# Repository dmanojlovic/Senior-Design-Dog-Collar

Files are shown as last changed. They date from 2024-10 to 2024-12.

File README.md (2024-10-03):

# Senior-Design-Dog-Collar
Welcome to our github page for our senior design project, below is a brief explanation of what is in each folder. Learn more about our progress [here](https://engineering.purdue.edu/477grp5/)

## Hierarchy PCB
This folder contains our PCB schematic in an easy to read format
## PCB
This folder contains our footprints, schematic and symbols for our PCB design
## Server
This folder contains all the files running on the server including the data processing, UART communication and website hosting
## STM
This folder contains all the files needed for the STM32 chip that will be on the dog collar

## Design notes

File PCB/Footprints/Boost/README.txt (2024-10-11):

## WEBENCH Design 21
Created at Fri Oct 11 11:33:55 CDT 2024
**********************************************************
***************** Schematic Instructions  ****************
**********************************************************

To import your new Schematic file into Eagle:

1. Unzip the downloaded folder files to local directory and Start Eagle.
2. Select "File"->"Open"->"Schematic..." from the menu at the top of
the screen.
3. Browse to your newly exported file and select the ".sch" file extension.
4. You should now see your schamtic available in Eagle.

**********************************************************
*******************  PCB Instructions  *******************
**********************************************************

To import your new BOARD file into Eagle:

1. Unzip the downloaded folder files to local directory and Start Eagle.
2. Select "File"->"Open"->"Board..." from the menu at the top of
the screen.
3. Browse to your newly exported file and select the ".brd" file extension.
4. Planes will need to be repoured to update the polygon fills
	1. Once your board is loaded, type "ratsnest" into the command
	   line and press the Enter key.
	2. The polygons should all be filled now.
5. You should now have an image of your board available in Eagle.

**********************************************************
*******************  LIB Instructions  *******************
**********************************************************

To import your new library into Eagle:

1. Start Eagle.
2. Select "File"->"New"->"Library" from the menu.
3. In the blank library window, select "File" -> "Execute Script"
from the menu.
5. Browse to your newly exported Eagle Script file (".scr" file extension)
6. After opening the file, the script will populate the new library.
Layer 93 should NOT exist.
7. Use "File"->Save As: "AcceleratedDesigns_Lib.lbr" and to the desired
location in Eagle native format.
8. Update schematic with the imported library, Select Library and click on Update; open the library file
	and sync. each part.

For additional information, please visit this site:
http://www.accelerated-designs.com/help/Eagle_import.html

You may also find this video helpful:
http://youtu.be/5jGuWY-Yy3Q

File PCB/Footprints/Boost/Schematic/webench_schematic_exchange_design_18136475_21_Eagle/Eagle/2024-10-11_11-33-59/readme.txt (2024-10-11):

 

**********************************************************
*************  Important Instructions Follow  ************
**********************************************************
 
All files exported to: C:\\CADExport\\workspace\Eagle\2024-10-11_11-33-59\2024-10-11_11-33-59

To import your new library into Eagle:
1. Start Eagle.
2. In the control panel window, Select File -> New -> Library from the menu.
3. In the blank library window, select File -> Execute Script from the menu.
5. Browse to your newly exported Eagle Script file (".scr" file extension)
6. After opening the file, the script will populate the new library.
7. Use File -> Save (or Save As..) to save the library to the desired location in Eagle native format.

**************************************************************
**    !!!!!!!!!!!!!        WARNING        !!!!!!!!!!!!!     **
**************************************************************

Besure to check the documentation layer, "48"/"Document", for important information that may seem to be missing or have not translated properly!

For additional information, please visit this site:
http://www.accelerated-designs.com/help/Eagle_import.html

You may also find this video helpful:
http://youtu.be/5jGuWY-Yy3Q

The Symbol WB_LM2735X was missing a Value attribute, a value was created for the symbol.

Ultra Librarian Gold 8.3.103 Process Report

Message - Padstack "RX44Y57D0T" Shape(4) is a CIRCLE with no diameter.
Message - Padstack "RX50Y22D0T" Shape(4) is a CIRCLE with no diameter.
Message - Padstack "RX45Y73D0T" Shape(4) is a CIRCLE with no diameter.
Message - Padstack "RX59Y87D0T" Shape(4) is a CIRCLE with no diameter.
Message - Pattern "SLF7045", entity (115-Line) is a LINE with matching start and end points.
Message - Pattern "SLF7045", entity (117-Line) is a LINE with matching start and end points.
Message - Pattern "SLF7045", entity (119-Line) is a LINE with matching start and end points.
Message - Pattern "SLF7045", entity (121-Line) is a LINE with matching start and end points.
Message - Symbol "WB_CAPACITOR" has as multiple attributes named "TYPE".
One of the attributes was renamed to "TYPE_2".

TextStyle count:  24
Padstack count:   4
Pattern count:    4
Symbol count:     8
Component count:  11

Export

Component "WB_GND" has no mapped footprint will be skipped.
Component "WB_BATTERY" has no mapped footprint will be skipped.
Component "WB_CURRENT_LOAD" has no mapped footprint will be skipped.

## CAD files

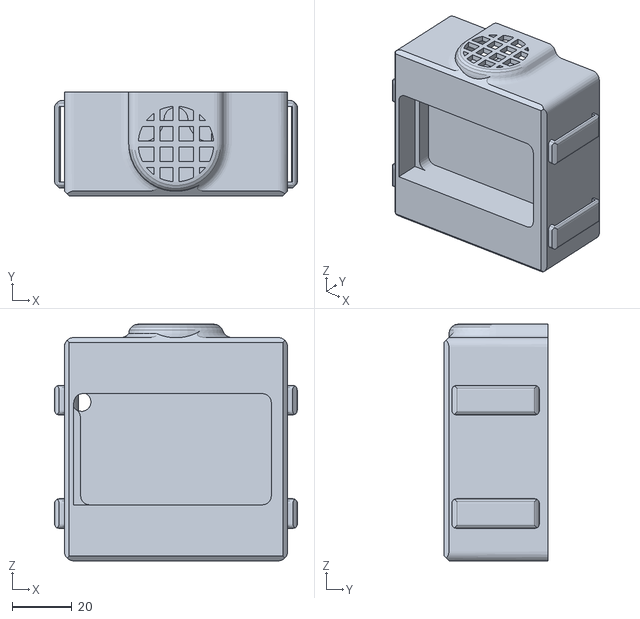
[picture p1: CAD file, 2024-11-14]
3d model/Dog Collar Box V2.2.stl
81.6 x 34.8 x 79.5

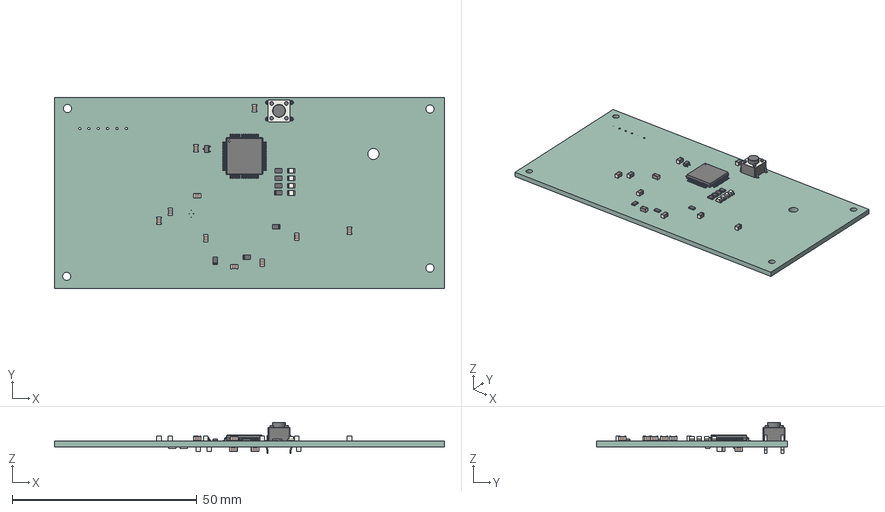
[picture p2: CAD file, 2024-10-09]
PCB/PCB.step
105.5 x 51.8 x 8.50 mm
C_0805_2012Metric x 16
SW_PUSH_6mm_h5mm
LED_0805_2012Metric x 4
R_0805_2012Metric x 9
LQFP_64_10x10mm_P05mm
SOT_323_SC_70
L_0805_2012Metric
_autosave-PCB_PCB

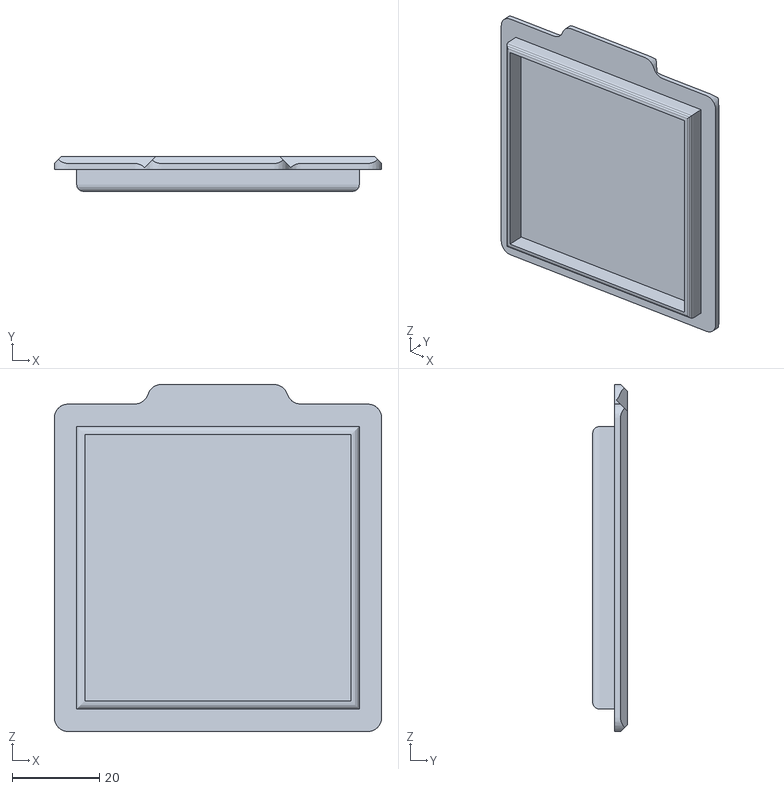
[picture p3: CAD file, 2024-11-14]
3d model/Dog Collar Box Lid V2.2.stl
75.0 x 8.00 x 79.5

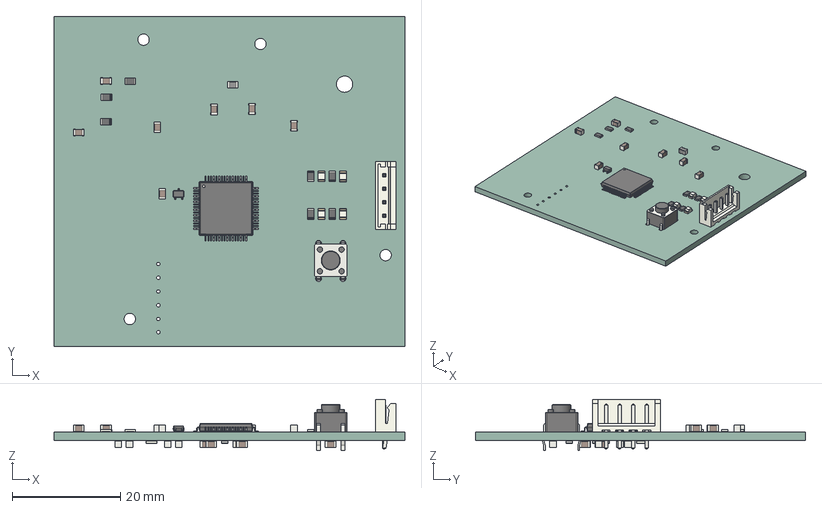
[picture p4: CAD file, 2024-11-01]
3d model/PCB.step
64.8 x 61.0 x 9.50 mm
R_0805_2012Metric x 11
L_0805_2012Metric
LQFP_64_10x10mm_P05mm
SOT_323_SC_70
SW_PUSH_6mm_h5mm
C_0805_2012Metric x 16
LED_0805_2012Metric x 4
JST_B4B_EH_A
PCB_PCB

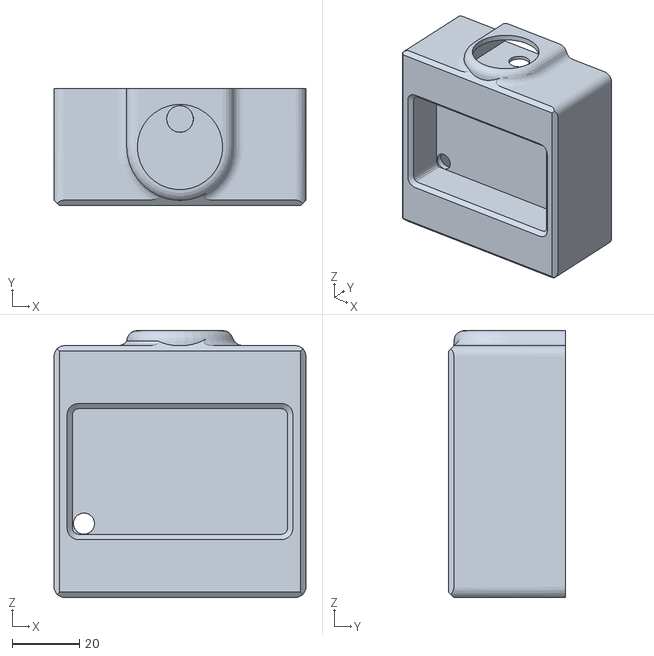
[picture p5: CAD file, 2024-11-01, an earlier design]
3d model/Dog Collar Box V2.1.stl
75.0 x 34.8 x 79.5

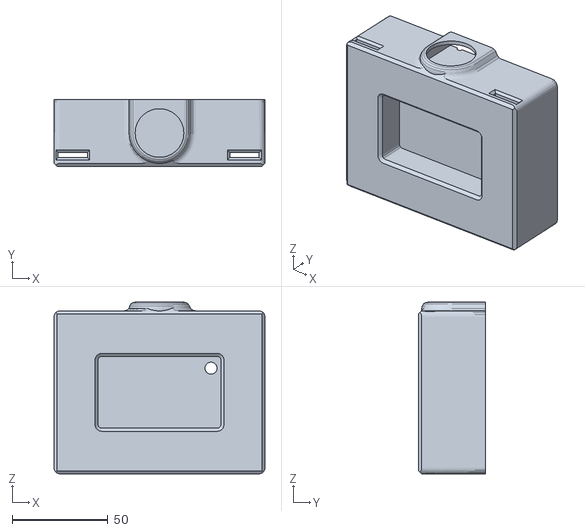
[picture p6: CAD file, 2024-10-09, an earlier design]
3d model/Dog Collar Box Lid V2.0.stl
110.0 x 34.8 x 89.5

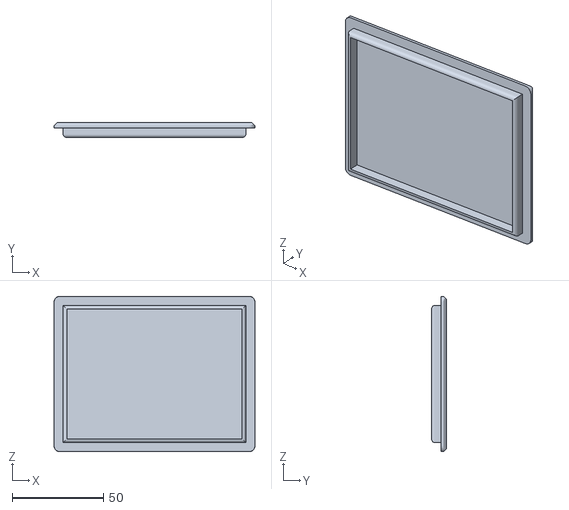
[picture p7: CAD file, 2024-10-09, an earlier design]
3d model/Dog Collar Box Lid V1.0.stl
110.0 x 8.00 x 85.0

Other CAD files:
3d model/Dog Collar Box V1.0.stl
3d model/Battery box.ipt
3d model/Dog Collar Box V1.0.iam
3d model/Dog Collar Box V1.0.idw
3d model/Lid.ipt
3d model/OldVersions/Battery box.0001.ipt
3d model/OldVersions/Dog Collar Box V1.0.0003.idw
3d model/OldVersions/Dog Collar Box V1.0.0007.iam
3d model/OldVersions/Lid.0004.ipt
3d model/OldVersions/PCB Holder.0005.ipt
3d model/PCB Holder.ipt
3d model/PCB/C_0805_2012Metric.iam
3d model/PCB/C_0805_2012Metric.ipt
3d model/PCB/LED_0805_2012Metric.iam
3d model/PCB/LED_0805_2012Metric.ipt
3d model/PCB/LQFP-64_10x10mm_P0.5mm.iam
3d model/PCB/LQFP_64_10x10mm_P05mm.ipt
3d model/PCB/L_0805_2012Metric.iam
3d model/PCB/L_0805_2012Metric.ipt
3d model/PCB/PCB.iam
3d model/PCB/R_0805_2012Metric.iam
3d model/PCB/R_0805_2012Metric.ipt
3d model/PCB/SOT-323_SC-70.iam
3d model/PCB/SOT_323_SC_70.ipt
3d model/PCB/SW_PUSH_6mm_H5mm.iam
3d model/PCB/SW_PUSH_6mm_h5mm.ipt
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

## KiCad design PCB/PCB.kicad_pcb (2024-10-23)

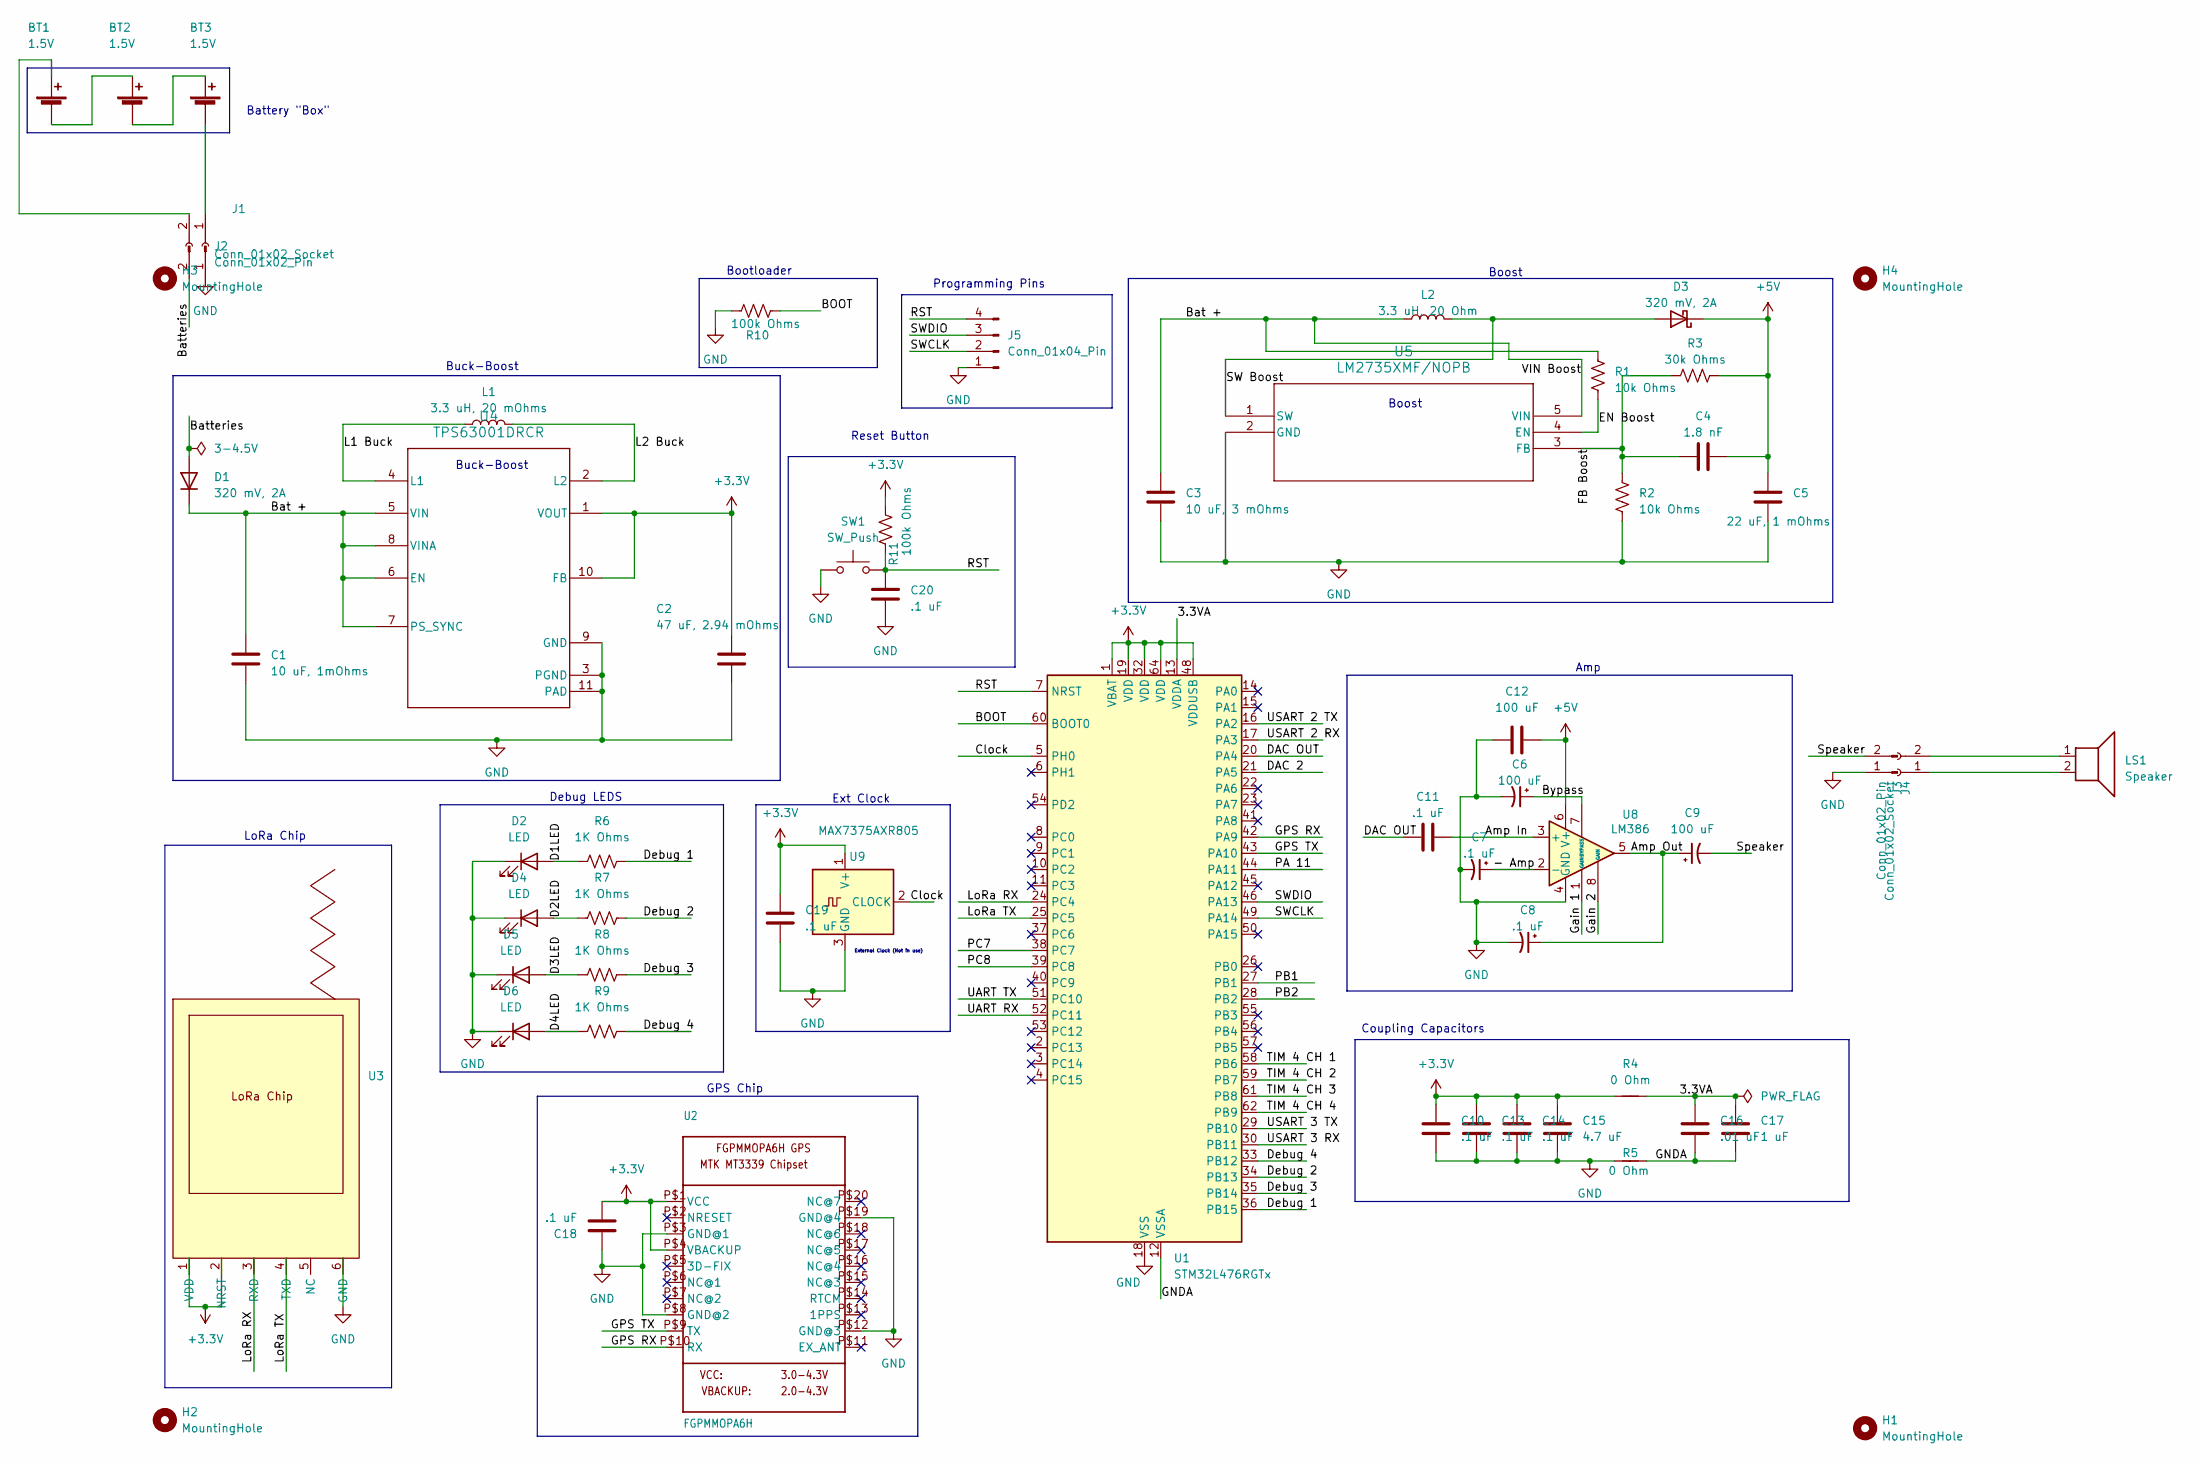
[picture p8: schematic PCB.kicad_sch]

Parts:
BT1, BT2, BT3: 1.5V
C1: 10 uF, 1mOhms; C_0805_2012Metric_Pad1.18x1.45mm_HandSolder
C2: 47 uF, 2.94 mOhms; C_0805_2012Metric_Pad1.18x1.45mm_HandSolder
C3: 10 uF, 3 mOhms; C_0805_2012Metric_Pad1.18x1.45mm_HandSolder
C4: 1.8 nF; C_0805_2012Metric_Pad1.18x1.45mm_HandSolder
C5: 22 uF, 1 mOhms; C_0805_2012Metric_Pad1.18x1.45mm_HandSolder
C6, C9: 100 uF; CAP_UZE_4X3P9_NCH
C7, C8: .1 uF; CAP_UZE_4X3P9_NCH
C10, C11, C13, C14, C18, C19, C20: .1 uF; C_0805_2012Metric_Pad1.18x1.45mm_HandSolder
C12: 100 uF; C_0805_2012Metric_Pad1.18x1.45mm_HandSolder
C15: 4.7 uF; C_0805_2012Metric_Pad1.18x1.45mm_HandSolder
C16: .01 uF; C_0805_2012Metric_Pad1.18x1.45mm_HandSolder
C17: 1 uF; C_0805_2012Metric_Pad1.18x1.45mm_HandSolder
D1, D3: 320 mV, 2A; Schottky
D2, D4, D5, D6: LED; LED_0805_2012Metric
H1, H2, H3, H4: MountingHole; MountingHole_2.1mm
J1, J4: Conn_01x02_Socket
J2, J3: Conn_01x02_Pin; JST_PH_B2B-PH-SM4-TB_1x02-1MP_P2.00mm_Vertical
J5: Conn_01x04_Pin; JST_EH_B4B-EH-A_1x04_P2.50mm_Vertical
L1: 3.3 uH, 20 mOhms; L_0805_2012Metric
L2: 3.3 uH, 20 Ohm; L_TDK_SLF7045
LS1: Speaker
R1, R2: 10k Ohms; R_0805_2012Metric_Pad1.20x1.40mm_HandSolder
R3: 30k Ohms; R_0805_2012Metric_Pad1.20x1.40mm_HandSolder
R4, R5: 0 Ohm; R_0805_2012Metric_Pad1.20x1.40mm_HandSolder
R6, R7, R8, R9: 1K Ohms; R_0805_2012Metric
R10, R11: 100k Ohms; R_0805_2012Metric
SW1: SW_Push; SW_PUSH_6mm_H5mm
U1: STM32L476RGTx; LQFP-64_10x10mm_P0.5mm
U2: FGPMMOPA6H
U3: LoRa Chip
U4: TPS63001DRCR; DRC0010J
U5: LM2735XMF/NOPB; MF05A
U8: LM386
U9: MAX7375AXR805; SOT-323_SC-70

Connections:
+3.3V: C2.1, C10.1, C13.1, C14.1, C15.1, C18.1, C19.1, R4.1, R11.2, U1.1 (VBAT), U1.19 (VDD), U1.32 (VDD), U1.48 (VDDUSB), U1.64 (VDD), U2.P$1 (VCC), U2.P$4 (VBACKUP), U3.1 (VDD), U3.2 (NRST), U4.1 (VOUT), U4.10 (FB), U9.1 (V+)
+5V: C4.2, C5.1, C12.1, D3.1 (K), R3.2, U8.6 (V+)
/3.3VA: C16.1, C17.1, R4.2, U1.13 (VDDA)
/- Amp: C7.1, U8.2 (-)
/Amp In: C11.2, U8.3 (+)
/Amp Out: C8.1, C9.1, U8.5
/BOOT: R10.2, U1.60 (BOOT0)
/Bat +: C1.1, C3.1, D1.1 (K), L2.1, R1.1, U4.5 (VIN), U4.6 (EN), U4.7 (PS_SYNC), U4.8 (VINA), U5.5 (VIN)
/Batteries: D1.2 (A), J2.2
/Bypass: C6.1, U8.7 (BYPASS)
/Clock: U1.5 (PH0), U9.2 (CLOCK)
/D1LED: D2.2 (A), R6.1
/D2LED: D4.2 (A), R7.1
/D3LED: D5.2 (A), R8.1
/D4LED: D6.2 (A), R9.1
/DAC 2: U1.21 (PA5)
/DAC OUT: C11.1, U1.20 (PA4)
/Debug 1: R6.2, U1.36 (PB15)
/Debug 2: R7.2, U1.34 (PB13)
/Debug 3: R8.2, U1.35 (PB14)
/Debug 4: R9.2, U1.33 (PB12)
/EN Boost: R1.2, U5.4 (EN)
/FB Boost: C4.1, R2.1, R3.1, U5.3 (FB)
/GNDA: C16.2, C17.2, R5.2, U1.12 (VSSA)
/GPS RX: U1.42 (PA9), U2.P$10 (RX)
/GPS TX: U1.43 (PA10), U2.P$9 (TX)
/Gain 1: U8.1 (GAIN)
/Gain 2: U8.8 (GAIN)
/L1 Buck: L1.1, U4.4 (L1)
/L2 Buck: L1.2, U4.2 (L2)
/LoRa RX: U1.24 (PC4), U3.3 (RXD)
/LoRa TX: U1.25 (PC5), U3.4 (TXD)
/PA 11: U1.44 (PA11)
/PB1: U1.27 (PB1)
/PB2: U1.28 (PB2)
/PC7: U1.38 (PC7)
/PC8: U1.39 (PC8)
/RST: C20.1, J5.4, R11.1, SW1.2, U1.7 (NRST)
/SW Boost: D3.2 (A), L2.2, U5.1 (SW)
/SWCLK: J5.2, U1.49 (PA14)
/SWDIO: J5.3, U1.46 (PA13)
/Speaker: C9.2, J3.2
/TIM 4 CH 1: U1.58 (PB6)
/TIM 4 CH 2: U1.59 (PB7)
/TIM 4 CH 3: U1.61 (PB8)
/TIM 4 CH 4: U1.62 (PB9)
/UART RX: U1.52 (PC11)
/UART TX: U1.51 (PC10)
/USART 2 RX: U1.17 (PA3)
/USART 2 TX: U1.16 (PA2)
/USART 3 RX: U1.30 (PB11)
/USART 3 TX: U1.29 (PB10)
GND: C1.2, C2.2, C3.2, C5.2, C6.2, C7.2, C8.2, C10.2, C12.2, C13.2, C14.2, C15.2, C18.2, C19.2, C20.2, D2.1 (K), D4.1 (K), D5.1 (K), D6.1 (K), J2.1, J3.1, J5.1, R2.2, R5.1, R10.1, SW1.1, U1.18 (VSS), U1.31 (VSS), U1.47 (VSS), U1.63 (VSS), U2.P$3 (GND@1), U2.P$8 (GND@2), U2.P$12 (GND@3), U2.P$19 (GND@4), U3.6 (GND), U4.3 (PGND), U4.9 (GND), U4.11 (PAD), U5.2 (GND), U8.4 (GND), U9.3 (GND)
unnamed: BT1.1 (+), J1.2
unnamed: BT1.2 (-), BT2.1 (+)
unnamed: BT2.2 (-), BT3.1 (+)
unnamed: BT3.2 (-), J1.1
unnamed: J4.1, LS1.2
unnamed: J4.2, LS1.1

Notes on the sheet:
Debug LEDS
External Clock (Not in use)
Programming Pins
Buck-Boost
Boost
Bootloader
LoRa Chip
Battery "Box"
GPS Chip
Boost
Amp
Reset Button
Coupling Capacitors
Ext Clock

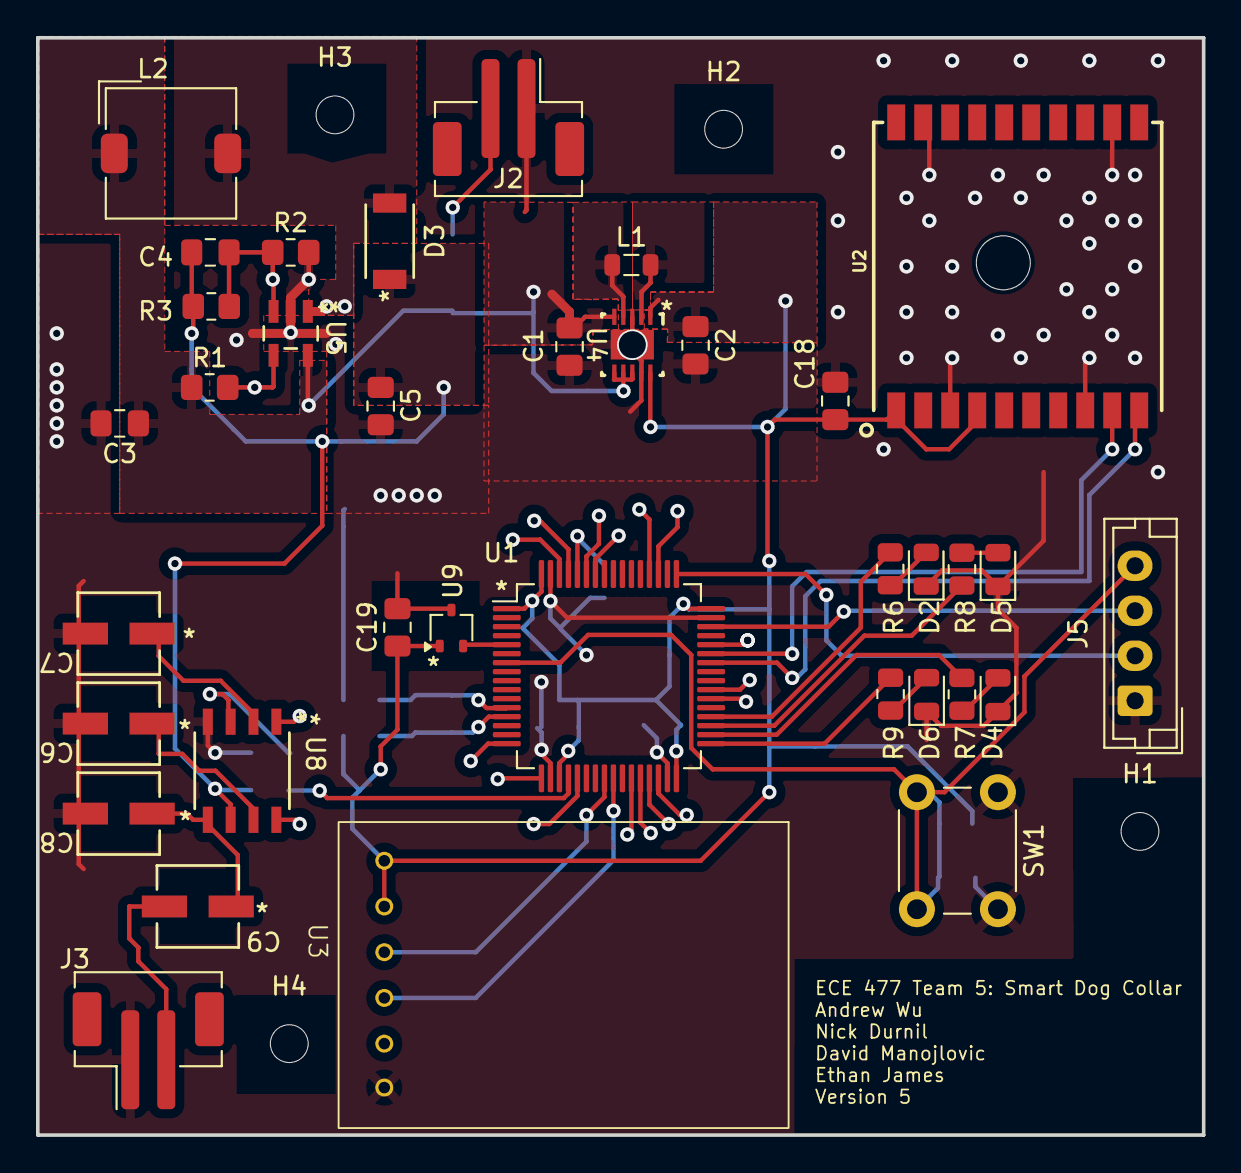
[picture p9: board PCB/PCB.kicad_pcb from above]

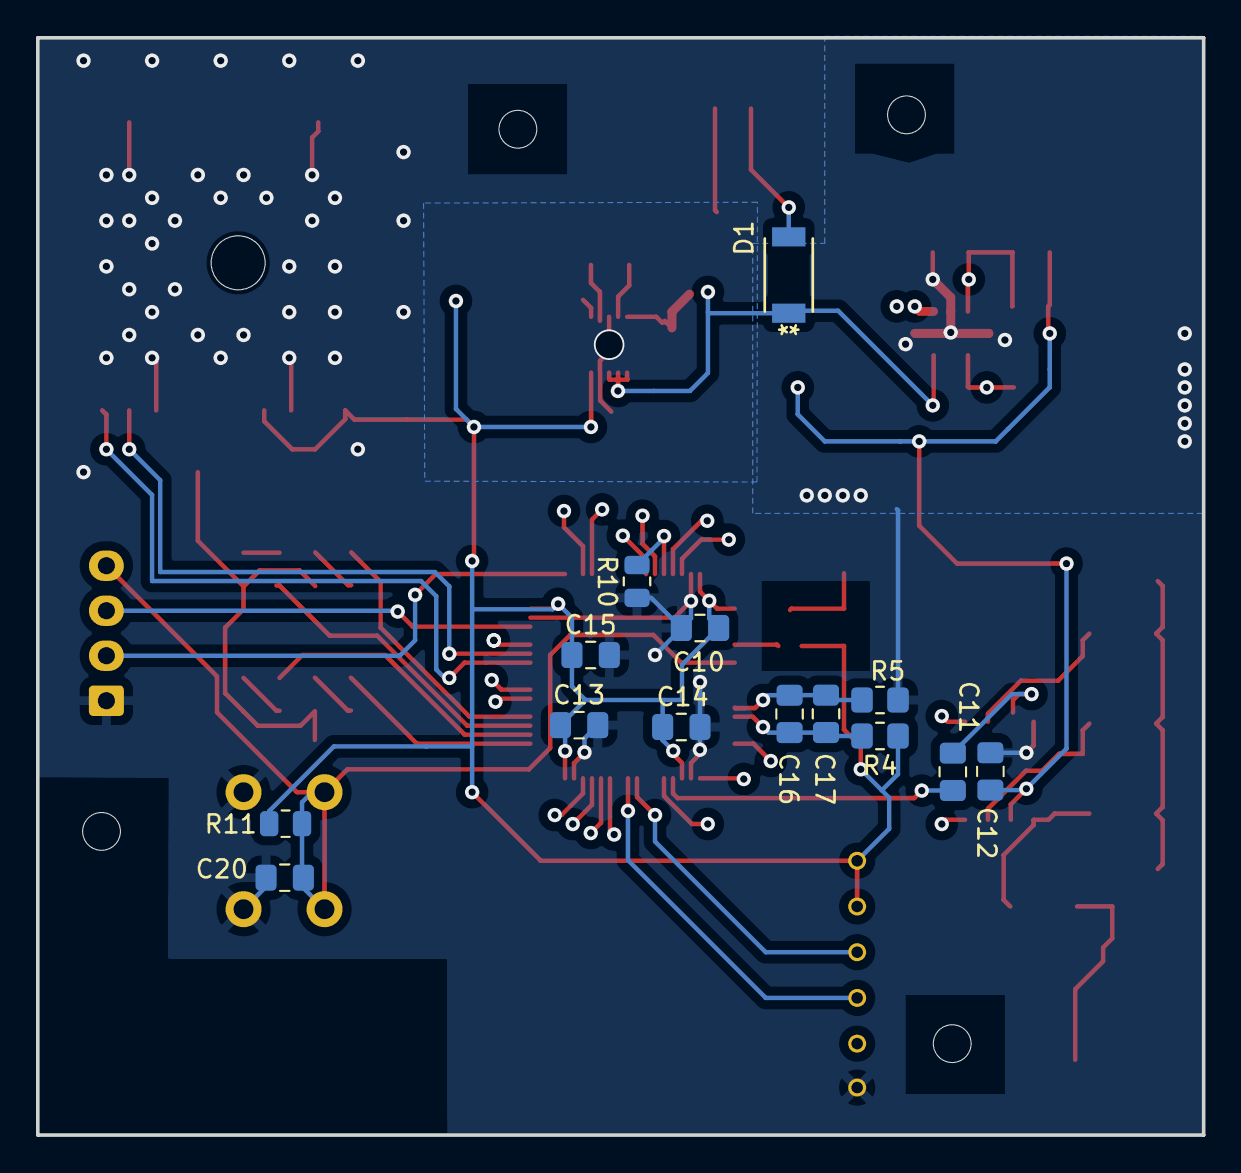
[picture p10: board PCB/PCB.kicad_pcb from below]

Board: 2 copper layers, 64.8 x 61.0 mm, 54 parts (14 on the bottom side), 35 nets.

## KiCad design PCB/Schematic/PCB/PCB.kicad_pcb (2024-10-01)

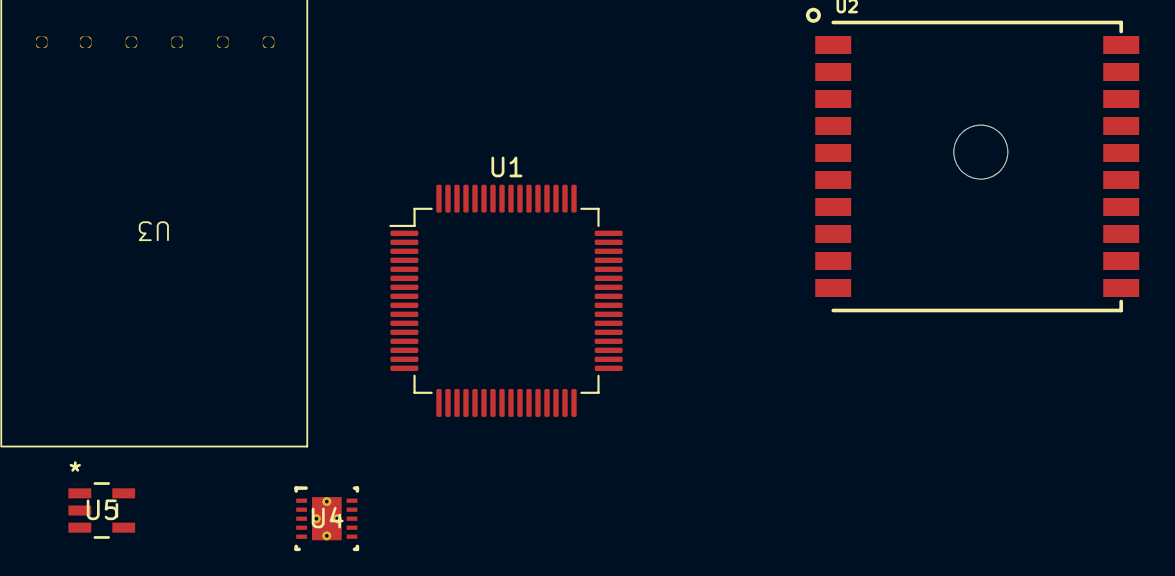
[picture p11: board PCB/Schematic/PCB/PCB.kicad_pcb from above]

Board: 2 copper layers, 5 parts (0 on the bottom side), 7 nets, no tracks yet.

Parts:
U1: STM32L476RGTx; LQFP-64_10x10mm_P0.5mm
U2: FGPMMOPA6H
U3: LoRa Chip
U4: TPS63001DRC; DRC0010J
U5: LM2735X; MF05A

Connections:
unnamed: U4.5 (VIN@5), U4.6 (EN@6), U4.7 (PS_SYNC@7), U4.8 (VINA@8), U5.5 (VIN@1)
unnamed: U1.14 (PA0), U2.P$10 (RX)
unnamed: U1.15 (PA1), U2.P$9 (TX)
unnamed: U1.53 (PC12), U3.3 (RXD)
unnamed: U1.54 (PD2), U3.4 (TXD)
unnamed: U1.1 (VBAT), U1.19 (VDD), U1.32 (VDD), U1.48 (VDDUSB), U1.64 (VDD), U2.P$1 (VCC), U2.P$4 (VBACKUP), U3.1 (VDD), U3.2 (NRST), U4.1 (VOUT@1), U4.10 (FB@10)
PAD: U1.18 (VSS), U1.31 (VSS), U1.47 (VSS), U1.63 (VSS), U2.P$3 (GND@1), U2.P$8 (GND@2), U2.P$12 (GND@3), U2.P$19 (GND@4), U3.6 (GND), U4.3 (PGND@3), U4.9 (GND@9), U4.11 (PAD@11), U5.2 (GND@5)

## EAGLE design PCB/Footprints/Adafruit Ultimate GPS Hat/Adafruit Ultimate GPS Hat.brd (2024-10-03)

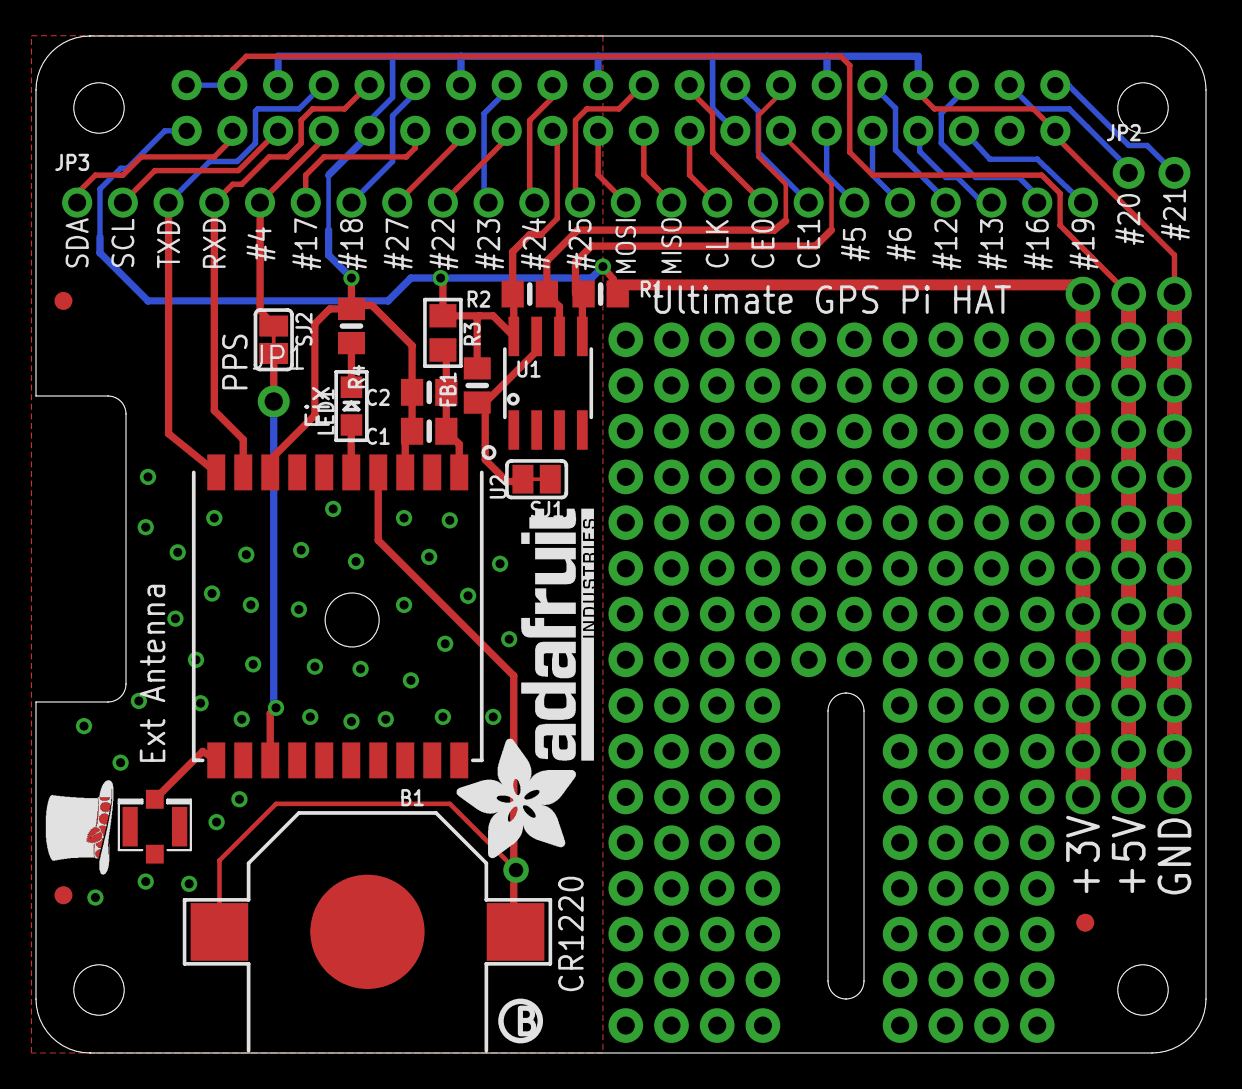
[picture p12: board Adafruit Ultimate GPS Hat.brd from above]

Board: 2 copper layers, 65.0 x 56.5 mm, 24 parts (0 on the bottom side), 37 nets.

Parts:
B1: CR1220
C1: 0.1uF; 0805-NO
C2: 10uF; 0805-NO
FB1: Ferrite; 0805
FID1, FID2, FID3: FIDUCIAL_1MM
JP1: 1X01-CLEANBIG
JP2: 1X02_ROUND
JP3: 1X23_ROUND_70MIL
LED1: RED; CHIPLED_0805
R1, R2, R3: 3.9K; 0805-NO
R4: 470; 0805-NO
RPI1: RASPBERRYPI_BPLUS_HATSLOTS; PI_HAT_SLOTS
SJ1: WP; SOLDERJUMPER_CLOSEDWIRE
SJ2: PPS; SOLDERJUMPER_CLOSEDWIRE
U1: CAT24C32; SOIC8_150MIL
U2: FGPMMOPA6H
U$3: ADAFRUIT_TEXT_20MM
U$4: PIHATLOGO
U$6: PCBFEAT-REV-056
U$20: U.FL

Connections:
1PPS: JP1.1, SJ2.2, U2.P$13
3.3V: FB1.1, R1.2, R2.2, R3.2, RPI1.1, RPI1.17, U1.8
5.0V: RPI1.2, RPI1.4
EECLK: R2.1, RPI1.28, U1.6
EEDATA: R1.1, RPI1.27, U1.5
FIX: LED1.A, U2.P$5
GND: B1.-, C1.2, C2.2, R4.1, RPI1.6, RPI1.9, RPI1.14, RPI1.20, RPI1.25, RPI1.30, RPI1.34, RPI1.39, SJ1.1, U1.1, U1.2, U1.3, U1.4, U2.P$3, U2.P$8, U2.P$12, U2.P$19, U$20.P$1, U$20.P$2
GPIO4: JP3.5, RPI1.7, SJ2.1
GPIO5: JP3.18, RPI1.29
GPIO6: JP3.19, RPI1.31
GPIO12: JP3.20, RPI1.32
GPIO13: JP3.21, RPI1.33
GPIO16: JP3.22, RPI1.36
GPIO17: JP3.6, RPI1.11
GPIO18: JP3.7, RPI1.12
GPIO19: JP3.23, RPI1.35
GPIO20: JP2.1, RPI1.38
GPIO21: JP2.2, RPI1.40
GPIO22: JP3.9, RPI1.15
GPIO23: JP3.10, RPI1.16
GPIO24: JP3.11, RPI1.18
GPIO25: JP3.12, RPI1.22
GPIO27: JP3.8, RPI1.13
unnamed: R3.1, SJ1.2, U1.7
unnamed: LED1.C, R4.2
unnamed: U2.P$11, U$20.P$3
RXD: JP3.4, RPI1.10, U2.P$9
SCL: JP3.2, RPI1.5
SDA: JP3.1, RPI1.3
SPI_CE0: JP3.16, RPI1.24
SPI_CE1: JP3.17, RPI1.26
SPI_MISO: JP3.14, RPI1.21
SPI_MOSI: JP3.13, RPI1.19
SPI_SCLK: JP3.15, RPI1.23
TXD: JP3.3, RPI1.8, U2.P$10
VBACKUP: B1.+$1, B1.+$2, U2.P$4
VCC: C1.1, C2.1, FB1.2, U2.P$1

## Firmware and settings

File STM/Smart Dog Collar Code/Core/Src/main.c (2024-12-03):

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
/* Includes ------------------------------------------------------------------*/
#include "main.h"

/* USER CODE BEGIN Includes */
#include "stm32l476xx.h"
#include "stm32l4xx.h"
#include <stdint.h>
#include <stdio.h>
#include <math.h>
#include <string.h>
/* USER CODE END Includes */

DAC_HandleTypeDef hdac1;
DMA_HandleTypeDef hdma_dac_ch1;

IWDG_HandleTypeDef hiwdg;

TIM_HandleTypeDef htim2;

UART_HandleTypeDef huart1;
UART_HandleTypeDef huart2;

void SystemClock_Config(void);
static void MX_GPIO_Init(void);
static void MX_DMA_Init(void);
static void MX_USART2_UART_Init(void);
static void MX_DAC1_Init(void);
static void MX_USART1_UART_Init(void);
static void MX_TIM2_Init(void);
static void MX_IWDG_Init(void);
/* USER CODE BEGIN PFP */
#ifdef __GNUC__
#define PUTCHAR_PROTOTYPE int __io_putchar(int ch)
#else
#define PUTCHAR_PROTOTYPE int fputc(int ch, FILE *f)
#endif

PUTCHAR_PROTOTYPE
{
  HAL_UART_Transmit(&huart2, (uint8_t *)&ch, 1, HAL_MAX_DELAY);
  return ch;
}

//LoRa uart and dma enable
void init_usart3(void); 
void enable_tty_interrupt(void);

//LoRa settings and sending data
void send_lora(char *, int, int);
void setup_lora(void);

//timer for GPS interrupt
void init_tim7();


/* USER CODE END PFP */

/* USER CODE BEGIN 0 */

//LoRa uart rolling buffer
#define FIFOSIZE 16
char serfifo[FIFOSIZE];
int seroffset = 0;

//LoRa buffers
#define LORA_BUF_SIZE 240
uint8_t tx_data_lora[LORA_BUF_SIZE]; 
uint8_t tx_received[24] = "AT+SEND=123,8,Received\r\n"; 
// uint8_t rx_data_lora[LORA_BUF_SIZE];

//GPS 
#define GNGGA_SIZE 36
uint8_t rx_data_gps[GNGGA_SIZE]; 
uint8_t isG;
uint8_t gpsbuf;

//Audio Sounds
const uint8_t zero[1] = {0};
extern const uint8_t stopCommand[18200];
extern const uint8_t whistle[24580];
extern const uint8_t Se7enNo[19316];

/* USER CODE END 0 */

/**
  * @brief  The application entry point.
  * @retval int
  */
int main(void)
{

  /* MCU Configuration--------------------------------------------------------*/

  /* Reset of all peripherals, Initializes the Flash interface and the Systick. */
  HAL_Init();

  /* Configure the system clock */
  SystemClock_Config();

  /* Initialize all configured peripherals */
  MX_GPIO_Init();
  MX_DMA_Init();
  MX_USART2_UART_Init();
  MX_DAC1_Init();
  MX_USART1_UART_Init();
  MX_TIM2_Init();
  MX_IWDG_Init();
  /* USER CODE BEGIN 2 */

  printf("Start of code\r\n");

  bzero(serfifo, FIFOSIZE);
  init_usart3();
  enable_tty_interrupt();
  setup_lora();

  init_tim7();

  HAL_GPIO_WritePin(GPIOB, GPIO_PIN_12, 0);
  HAL_GPIO_WritePin(GPIOB, GPIO_PIN_13, 0);
  HAL_GPIO_WritePin(GPIOB, GPIO_PIN_14, 0);
  HAL_GPIO_WritePin(GPIOB, GPIO_PIN_15, 0);

  HAL_TIM_Base_Start_IT(&htim2);

  // HAL_DAC_Start_DMA(&hdac1, DAC_CHANNEL_1, (uint8_t*)zero, 1, DAC_ALIGN_8B_R);

  // HAL_Delay(5000);
  // HAL_TIM_Base_Start_IT(&htim7);
  

  // HAL_NVIC_SetPriority(TIM7_IRQn, 15, 0);
  // HAL_NVIC_SetPriority(USART3_IRQn, 0, 0);

  /* USER CODE END 2 */

  /* Infinite loop */
  /* USER CODE BEGIN WHILE */
  while (1)
  {
    /* USER CODE END WHILE */

    /* USER CODE BEGIN 3 */

    // while (!(USART3->ISR & USART_ISR_RXNE)) { }
    // char c = USART3->RDR;
    // while(!(USART3->ISR & USART_ISR_TXE)) { }
    // USART3->TDR = c;

    // HAL_DAC_Start_DMA(&hdac1, DAC_CHANNEL_1, (uint8_t*)stopCommand, 18200, DAC_ALIGN_8B_R);
    // HAL_GPIO_TogglePin(GPIOA, GPIO_PIN_5);
    HAL_Delay(1000);
    HAL_IWDG_Refresh(&hiwdg);

  }

  
  /* USER CODE END 3 */
}

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
/* USER CODE BEGIN 4 */

void setup_lora(void){
  
  HAL_Delay(200);
  send_lora("AT\r\n", 4, 5); //basic stm to lora check (rcv: +OK)
  // HAL_Delay(200);
  // send_lora("AT+FACTORY\r\n", 12, 8); //set to factory default (rcv: +FACTORY)
  HAL_Delay(200);
  send_lora("AT+ADDRESS=124\r\n", 16, 5); //set lora address (rcv: +OK)
  HAL_Delay(200);
  send_lora("AT+NETWORKID=7\r\n", 16, 5); //set network id (rcv: +OK)
  HAL_Delay(200);
  send_lora("AT+CPIN=102C064CA409E69030F73E7CABAA4B71\r\n", 42, 5); //set AES pin (rcv: +OK)
  HAL_Delay(200);

  printf("Done setting up LoRa\r\n");
  HAL_IWDG_Refresh(&hiwdg);
}

void send_lora(char *msg, int size, int resp_size){
  bzero(tx_data_lora, LORA_BUF_SIZE);
  // bzero(rx_data_lora, LORA_BUF_SIZE);
  memcpy(tx_data_lora, msg, size);

  for(int i = 0; i < size; i++){ //transmit each char, one at a time
    while(!(USART3->ISR & USART_ISR_TXE)) { }
    USART3->TDR = tx_data_lora[i];
  }
  HAL_IWDG_Refresh(&hiwdg);

  // while(HAL_UART_Receive(&huart3, rx_data_lora, resp_size, 1000)!=HAL_OK){}
  // HAL_UART_Transmit(&huart2, serfifo, resp_size, 10);
}


void init_usart3() { //LoRa
    RCC->AHB2ENR |= RCC_AHB2ENR_GPIOCEN; //turn on GPIO C
    GPIOC->MODER &= ~(GPIO_MODER_MODER4 | GPIO_MODER_MODER5); //clear pc12
    GPIOC->MODER |= GPIO_MODER_MODER4_1 | GPIO_MODER_MODER5_1; //PC12 as alternate function

    GPIOC->AFR[0] &= ~0x00ff0000; //AF7
    GPIOC->AFR[0] |=  0x00770000; 

    RCC->APB1ENR1 |= RCC_APB1ENR1_USART3EN; //enable usart5 clock
    USART3->CR1 &= ~USART_CR1_UE; //disable usart3

    USART3->CR1 &= ~USART_CR1_M; //set word size to 8 by clearing M0 and M1
    USART3->CR2 &= ~USART_CR2_STOP; //one stop bit
    USART3->CR1 &= ~USART_CR1_PCE; //disable parity bit
    USART3->CR1 &= ~USART_CR1_OVER8; //16x oversampling
    USART3->BRR = 40000000/115200; //Baud rate of 115200 (table 249)
    USART3->CR1 |= USART_CR1_TE; //enable transmitter
    USART3->CR1 |= USART_CR1_RE; //enable receiver

    USART3->CR1 |= USART_CR1_UE; //enable usart5

    while(!(USART3->ISR & (USART_ISR_TEACK | USART_ISR_REACK))); //wait for TE and RE to be acknowledged
    HAL_IWDG_Refresh(&hiwdg);
}

void enable_tty_interrupt(void) {
    // TODO
    USART3->CR1 |= USART_CR1_RXNEIE; //enable interupt when receive data register becomes not empty.
    NVIC->ISER[1] = 1 << (USART3_IRQn-32);

    USART3->CR3 |= USART_CR3_DMAR; //enable DMA mode
    RCC->AHB1ENR |= RCC_AHB1ENR_DMA1EN; //Enable DMA1 clock

    DMA1_CSELR->CSELR &= ~0x00000f00; //clear channel 3
    DMA1_CSELR->CSELR |=  0x00000200; //select channel 3 to be usart3rx
    DMA1_Channel3->CCR &= ~DMA_CCR_EN; //disable dma1 channel 3

    DMA1_Channel3->CMAR = (uint32_t) serfifo; //set memory address
    DMA1_Channel3->CPAR = (uint32_t) &(USART3->RDR); //set peripheral address
    DMA1_Channel3->CNDTR = FIFOSIZE; //number of elements you are trying to transfer
    DMA1_Channel3->CCR &= ~DMA_CCR_DIR; //dir set to from-p-to-m
    DMA1_Channel3->CCR |= DMA_CCR_MINC; //minc set to increment memory
    DMA1_Channel3->CCR &= ~DMA_CCR_PINC; //pinc disabled
    DMA1_Channel3->CCR &= ~(DMA_CCR_PSIZE | DMA_CCR_MSIZE); //MSIZE and PSIZE set to 8 bits
    DMA1_Channel3->CCR |= DMA_CCR_CIRC; //circ enabled
    DMA1_Channel3->CCR &= ~(DMA_CCR_TCIE | DMA_CCR_HTIE | DMA_CCR_TEIE); //disable total and half transfer interrupt
    DMA1_Channel3->CCR &= ~DMA_CCR_MEM2MEM; //disable mem2mem
    DMA1_Channel3->CCR |= DMA_CCR_PL; //set priority level to highest

    DMA1_Channel3->CCR |= DMA_CCR_EN; //enable dma1 channel 3
}

void USART3_IRQHandler(void){
  // while(DMA1_Channel3->CNDTR != sizeof serfifo - seroffset) //printing character
  // {
  //   while(!(USART3->ISR & USART_ISR_TXE)) { }
  //   USART3->TDR = serfifo[seroffset];
  //   seroffset = (seroffset + 1) % sizeof serfifo;
  // }

  // while(DMA1_Channel3->CNDTR != sizeof serfifo - seroffset)
  // { 
  //   // while(!(USART3->ISR & USART_ISR_TXE)) { }
  //   // USART3->TDR = serfifo[seroffset];
  //   // HAL_UART_Transmit(&huart2, serfifo[seroffset], 1, 10);
  //   printf("Hello ");

  //   seroffset = (seroffset + 1) % sizeof serfifo;
  // }

  // printf("%c", serfifo[seroffset]);
  // if(seroffset == 0){
  //   printf("%c%c", serfifo[FIFOSIZE-1], serfifo[seroffset]);
  // }else{
  //   printf("%c%c", serfifo[seroffset-1], serfifo[seroffset]);
  // }

  while(DMA1_Channel3->CNDTR != sizeof serfifo - seroffset){
    printf("%c", serfifo[seroffset]);
    // HAL_GPIO_TogglePin(GPIOB, GPIO_PIN_13);
    uint8_t audio_cue = serfifo[seroffset];
    // printf("%c", audio_cue);

    if(audio_cue == 'a'){
      // printf("Audio %c", audio_cue);
       HAL_GPIO_TogglePin(GPIOB, GPIO_PIN_12);
       HAL_DAC_Start_DMA(&hdac1, DAC_CHANNEL_1, (uint8_t*)whistle, 24580, DAC_ALIGN_8B_R);
        for(int i = 0; i < 24; i++){ //send received signal
          while(!(USART3->ISR & USART_ISR_TXE)) { }
          USART3->TDR = tx_received[i];
        }
     }
     else if(audio_cue == 'b'){
      // printf("Audio %c", audio_cue);
       HAL_GPIO_TogglePin(GPIOB, GPIO_PIN_12);
       HAL_DAC_Start_DMA(&hdac1, DAC_CHANNEL_1, (uint8_t*)stopCommand, 18200, DAC_ALIGN_8B_R);
        for(int i = 0; i < 24; i++){ //send received signal
          while(!(USART3->ISR & USART_ISR_TXE)) { }
          USART3->TDR = tx_received[i];
        }
     }
     else if(audio_cue == 'd'){
      // printf("Audio %c", audio_cue);
       HAL_GPIO_TogglePin(GPIOB, GPIO_PIN_12);
       // HAL_DAC_Start_DMA(&hdac1, DAC_CHANNEL_1, (uint8_t*)noCommand, 22332, DAC_ALIGN_8B_R);
       HAL_DAC_Start_DMA(&hdac1, DAC_CHANNEL_1, (uint8_t*)Se7enNo, 19316, DAC_ALIGN_8B_R);
        for(int i = 0; i < 24; i++){ //send received signal
          while(!(USART3->ISR & USART_ISR_TXE)) { }
          USART3->TDR = tx_received[i];
        }

     }
    //  else if(audio_cue == 'D'){
    //    HAL_GPIO_TogglePin(GPIOB, GPIO_PIN_12);
    //    // HAL_DAC_Start_DMA(&hdac1, DAC_CHANNEL_1, (uint8_t*)comeHome, 22908, DAC_ALIGN_8B_R);
    //  }
    
    // if((audio_cue == 'A') || (audio_cue == 'B')||(audio_cue == 'D')){
    //   for(int i = 0; i < 24; i++){ //send received signal
    //     while(!(USART3->ISR & USART_ISR_TXE)) { }
    //     USART3->TDR = tx_received[i];
    //   }
    // }
    
    
    seroffset = (seroffset + 1) % sizeof serfifo;
  }

  // printf("%c", serfifo[seroffset]);
  // HAL_GPIO_TogglePin(GPIOB, GPIO_PIN_13);
  // if((serfifo[seroffset] == 'A') || (serfifo[seroffset] == 'B') || (serfifo[seroffset] == 'C')){
  //   HAL_GPIO_TogglePin(GPIOB, GPIO_PIN_12);

  //   for(int i = 0; i < 24; i++){ //send received signal
  //     while(!(USART3->ISR & USART_ISR_TXE)) { }
  //     USART3->TDR = tx_received[i];
  //   }
  //   // send_lora(tx_received, 24, 5);
  //   // printf("Data sent\r\n");
  // }
  
  // seroffset = (seroffset + 1) % sizeof serfifo;
  

  // send_lora(tx_received, 24, 5);
  HAL_IWDG_Refresh(&hiwdg);
}



void TIM7_IRQHandler(void)
{
  TIM7->SR &= ~TIM_SR_UIF; //acknowledge the interrupt

  // printf("Start of GPS interrupt\r\n");
  HAL_GPIO_TogglePin(GPIOB, GPIO_PIN_14);

  isG = 0;
  while(1){
    HAL_UART_Receive(&huart1, &gpsbuf, 1, 10);
    if(gpsbuf == 'G'){ //G found
      isG = 1;
    }
    else if(isG == 1){
      if(gpsbuf == 'A'){ //GA found
        HAL_UART_Receive(&huart1, rx_data_gps, GNGGA_SIZE, 100);
        break;
      }
      else{
        isG = 0;
      }

    }
  } 

  // printf("GPS DATA: %s\n\r", rx_data_gps);
  // printf("Parsed: %s\n\r", rx_data_gps+12);
  
  
  // HAL_UART_Transmit(&huart3, txsend, strlen(txsend), 1000);
  // bzero(rx_data_lora, GNGGA_SIZE);
  // for(int i = 0; i < 38; i++){ //send received signal
  //   while(!(USART3->ISR & USART_ISR_TXE)) { }
  //   USART3->TDR = txsend[i];
  // }

  

  if(rx_data_gps[12] == ','){ //No fix found
    HAL_GPIO_WritePin(GPIOB, GPIO_PIN_15, 1);
    HAL_GPIO_WritePin(GPIOB, GPIO_PIN_13, 0);
  }else{ //fix found
    HAL_GPIO_WritePin(GPIOB, GPIO_PIN_15, 0);
    HAL_GPIO_WritePin(GPIOB, GPIO_PIN_13, 1);

    // uint8_t temp[25] = "4025.7373,N,08654.7737,W";
    uint8_t txsend[41] = "AT+SEND=123,24,";
    strncat(txsend, rx_data_gps+12,24);
    // strncat(txsend, temp,24);
    strncat(txsend, "\r\n",2);
    // printf("RX gps: %s", txsend);

    // uint8_t temp2[41] = "AT+SEND=123,24,4025.7373,N,08654.7737,W\r\n"; 
    for(int i = 0; i < 41; i++){ //send received signal
      while(!(USART3->ISR & USART_ISR_TXE)) { }
      USART3->TDR = txsend[i];
      // USART3->TDR = temp2[i];
    }

    // uint8_t tx_received[24] = "AT+SEND=123,8,Received\r\n"; 
    // for(int i = 0; i < 24; i++){ //send received signal
    //     while(!(USART3->ISR & USART_ISR_TXE)) { }
    //     USART3->TDR = tx_received[i];
    //   }
  }

  bzero(rx_data_gps, GNGGA_SIZE);
  HAL_IWDG_Refresh(&hiwdg);

  /* USER CODE END TIM7_IRQn 1 */
}

void init_tim7() {
    RCC->APB1ENR1 |= RCC_APB1ENR1_TIM7EN; //enable TIM7 clock

    //period(sec) = (ARR * PSC) / CLK
    int period = 10;
    TIM7->PSC = 20000 - 1; //prescaler
    TIM7->ARR = (2000*period)- 1; //auto reload register
    TIM7->DIER |= TIM_DIER_UIE; //update interrupt enable
    NVIC->ISER[1] |= 1 << (TIM7_IRQn-32); //enable interrupt in nvic
    TIM7->CR1 |= TIM_CR1_CEN; //start timer
}


/* USER CODE END 4 */
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


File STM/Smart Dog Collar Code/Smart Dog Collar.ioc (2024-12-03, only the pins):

Mcu.UserName=STM32L476RGTx
PA10.Signal=USART1_RX
PA2.Signal=USART2_TX
PA3.Signal=USART2_RX
PA4.Signal=COMP_DAC11_group
PA9.Signal=USART1_TX
PB12.Signal=GPIO_Output
PB13.Signal=GPIO_Output
PB14.Signal=GPIO_Output
PB15.Signal=GPIO_Output
PC13.Signal=GPIO_Input
PC3.Signal=GPXTI3
PC4.Signal=USART3_TX
PC5.Signal=USART3_RX

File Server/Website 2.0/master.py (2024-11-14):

import serial
import time
import sys
from UART import *
from dataSave import *
from conversion import *
import RPi.GPIO as GPIO

def master():
    ser = init_uart(port='/dev/ttyS0', baudrate=115200, timeout=.1)
    if ser:
        send_at_command(ser, 'AT+ADDRESS=123')  # Example to set LoRa address
        send_at_command(ser, 'AT+NETWORKID=7')  # Example to set LoRa network ID
        send_at_command(ser, 'AT+CPIN=102C064CA409E69030F73E7CABAA4B71')
    return ser

def GPIOSetup():
    GPIO.setmode(GPIO.BCM)
    GPIO.setwarnings(False)
    GPIO.setup(5,GPIO.OUT)
    GPIO.output(5,0)
    GPIO.setup(6,GPIO.OUT)
    GPIO.output(6,0)
    
def sendCommand(channel):
    if(GPIO.input(6) & GPIO.input(5)):
        print("3")
        GPIOReset()
    elif(GPIO.input(6) & ~GPIO.input(5)):
        print("2")
        GPIOReset()
    elif(~GPIO.input(6) & GPIO.input(5)):
        print("1")
        GPIOReset()

def GPIOReset():
    GPIO.output(5,0)
    GPIO.output(6,0)
    
def playAudio(audio:str):
    start = time.time()
    send_at_command(ser, 'AT+SEND=124,1,' + audio)
    while True:
        if((time.time() - start) > 3):
            send_at_command(ser, 'AT+SEND=124,1,' + audio)
            start = time.time()
        response = ser.readline()
        if(b'Received' in response):
            break
    
    print("Data sent sucessfully") 

def borderCheck(lat, lng):
    data = {}
    with open('public/geofence.json', 'r') as file:
        data = json.load(file)
    if lng > data["west"] and lng < data["east"] and lat > data["south"] and lat < data["north"]:
        pass
    else:
        playAudio("B")

if __name__ == '__main__':
    ser = master()
    GPIOSetup()
    
    while True:
        send = "0"
        response = ""
        response = ser.readline()
        if(b'RCV' in response):
            print(response)
            try:
                packet = str(response).split(",")
                data = packet[2:-2]
                lat = data[2] + data[3]
                lng = data[4] + data[5]
                lng, lat = NMEAConv(lng, lat)
                RSSI = int(packet[-2])
                SNR = packet[-1]
                SNR = int(SNR[:-5])
                
                strengthNum = 0
                if(RSSI < -115 and RSSI >= -126):
                    strengthNum += 1
                elif(RSSI < -126):
                    strengthNum += 2
                if(SNR < -7 and SNR >= -15):
                    strengthNum += 1
                elif(SNR < -15):
                    strengthNum += 2
                
                match strengthNum:
                    case 0:
                        strength = "Good"
                    case 1:
                        strength = "Fair"
                    case 2:
                        strength = "Poor"
                    case 3:
                        strength = "Poor"
                    case _:
                        strength = "Bad"
                print("saving")
                conv(lng, lat, strength)
                print("Checking bounds")
                borderCheck(lat,lng)
            except:
                print("Improper data")
        elif(GPIO.input(5) and not GPIO.input(6)):
            GPIOReset()
            playAudio("A")
        elif(GPIO.input(6) and not GPIO.input(5)):
            GPIOReset()
            playAudio("B")
        elif(GPIO.input(5) and GPIO.input(6)):
            GPIOReset()
            playAudio("C")
        sys.stdout.flush()
    sys.exit(master(sys.argv))

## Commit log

2024-09-03 Update UART.py
    I altered the port location to reflect the actual port configured for UART.
2024-09-04 website and uart commit
2024-09-17 adding stm32 code
2024-10-01 Add files via upload
    KiCad files for the PCB schematic
    [PCB.kicad_pcb, PCB.kicad_sch]
2024-10-01 PCB desingn
    I added the files with the updated pages where someone will need to recreate each connection within the pages. The untitled schematic represents the Lora Chip which I forgot to change the name.
    [BatteryBox.kicad_sch, Boost.kicad_sch, Buck_Boost.kicad_sch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]
2024-10-02 Updated the indivdual components.
    Some of the individual components still need to be updated and completed. With the battery box, include the diode. The full schematic is not the update one as Andrew has the updated one with the correct flyback diode placement.
    [Boost.kicad_sch, Buck_Boost.kicad_sch, GPS.kicad_sch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]
2024-10-03 removed battery life
2024-10-03 moved into folder
    [BatteryBox.kicad_sch, Boost.kicad_sch, Buck_Boost.kicad_sch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]
2024-10-03 Add files via upload
    "Completed" schematic and started layout
    [PCB.kicad_pcb, PCB.kicad_sch]
2024-10-03 Add files via upload
    Updated footprints
    [Adafruit Ultimate GPS Hat.brd, Adafruit Ultimate GPS Hat.kicad_sch]
2024-10-09 Add files via upload
    Need to decide how big the ground plane is, where to place the GPS, and connect the LoRa and GPS traces.
    Also need to add silkscreen layer and make sure checks in PCB verification checklist are completed.
    [PCB.kicad_pcb, PCB.kicad_sch]
2024-10-09 changed pcb
    [PCB.kicad_pcb, PCB.kicad_sch]
2024-10-09 Added a few things for presentation purposes
    [PCB.kicad_sch]
2024-10-09 Formatting on the Overall schematic
    [PCB.kicad_sch]
2024-10-09 Few more formatting things
    [PCB.kicad_sch]
2024-10-09 Updated Micro in hieracrchy
    [Micro.kicad_sch]
2024-10-09 updated micro hierarachy slightly
    [Micro.kicad_sch]
2024-10-09 Changed name from unitled to lora so its more clear
    [lora.kicad_sch, untitled.kicad_sch]
2024-10-09 3d model fix
    [Battery box.0001.ipt, Battery box.ipt, C_0805_2012Metric.iam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]
2024-10-10 pcb changes
    [PCB.kicad_sch]
2024-10-11 Schematic cleaned up
    [PCB.kicad_pcb, PCB.kicad_sch]
2024-10-11 pcb fix
    [PCB.kicad_pcb, PCB.kicad_sch]
2024-10-11 minor pcb changes
    [PCB.kicad_pcb, PCB.kicad_sch]
2024-10-11 minor pcb tweaks
    [2024-10-11_11-33-58.sch, PCB.kicad_pcb, PCB.kicad_sch]
2024-10-11 Add files via upload
    Finished PCB, awaiting check from professor and TAs
    [PCB.kicad_pcb, PCB.kicad_sch]
2024-10-16 Exlusion Zones added
    [PCB.kicad_pcb]
2024-10-16 DRC Error fixes
    [PCB.kicad_pcb]
2024-10-16 Debug vias added
    [PCB.kicad_pcb, PCB.kicad_sch]
2024-10-16 silkscreen visibility fix
    [PCB.kicad_pcb]
2024-10-16 tweaks based on email
    [PCB.kicad_pcb]
2024-10-16 version change on silk screan
    [PCB.kicad_pcb]
2024-10-17 run python script on button call
2024-10-17 pcb v5
    [PCB.kicad_pcb, PCB.kicad_sch]
2024-10-17 gbr files
    [PCB-B_Cu.gbr, PCB-B_Mask.gbr, PCB-B_Paste.gbr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]
2024-10-17 gbr file fixes
    [PCB-B_Cu.gbr, PCB-B_Mask.gbr, PCB-B_Paste.gbr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]
2024-10-17 untented vias
    [PCB-B_Cu.gbr, PCB-B_Mask.gbr, PCB-B_Paste.gbr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]
2024-10-23 updated stm code. Includes GPS interrupt, LoRa send/receive, and play audio
2024-10-30 Integrated code
    [Smart Dog Collar Debug.cfg]
2024-11-01 3d model fixed
    [Dog Collar Box V1.0.stl, PCB Holder.ipt, PCB.step]
2024-11-01 tolerance fix
    [Dog Collar Box V2.1.stl, PCB Holder.ipt]
2024-11-14 Server Demo
    [Dog Collar Box Lid V2.2.stl, Dog Collar Box V1.0.iam, Dog Collar Box V2.2.stl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]
2024-12-03 Updated interrupt code for Spark Challenge (after demo code)

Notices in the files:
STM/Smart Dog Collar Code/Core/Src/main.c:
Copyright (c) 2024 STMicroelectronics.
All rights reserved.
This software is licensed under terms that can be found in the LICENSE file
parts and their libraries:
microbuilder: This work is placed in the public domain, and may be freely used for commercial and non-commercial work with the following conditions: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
